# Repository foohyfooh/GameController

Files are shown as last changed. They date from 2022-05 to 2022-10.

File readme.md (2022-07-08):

# Game Controller

This is my attempt to make a custom PC game controller which has all of the regular buttons expected as well as has the ability to switch the positions of the face buttons between the Nintendo and Xbox conventions.

## [V1.0 - Initial Idea](V1.0)
- [Readme](V1.0/readme.md)
- [Schematic](V1.0/circuit.png)

This is the first iteration of the controller design based on my limited electronics experience which uses an Arduino Nano 33 BLE.

## [V1.1 - Intial Revision](V1.1)
- [Readme](V1.1/readme.md)
- [Schematic](V1.1/schematic.png)
- [Code](V1.1/code/code.ino)

This is the second iteration updated with feedback from coworkers from my inital version.

## [V1.2 - Second Revision](V1.2)
- [Readme](V1.2/readme.md)
- [Controller Schematic](V1.2/schematic-Controller.png)
- [Power Schematic](V1.2/schematic-Power.png)
- [Code](V1.2/code/code.ino)

This is the third iteration where I added in a voltage regulator component.

## [V2.0 - Third Revision](V2.0)
- [Readme](V2.0/readme.md)
- [Schematic](V2.0/schematic.png)
- [Code](V2.0/code/code.ino)

This is the fourth iteration which changes the microcontroller to the Arduino Micro since the joystick library I want to use doesn't support the Arduino Nano 33 BLE.

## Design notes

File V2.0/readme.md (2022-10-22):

# Game Controller Design Version 2.0

The main idea is to make a PC controller using [Arduino Micro](https://store.arduino.cc/products/arduino-micro), [slim buttons](https://www.adafruit.com/product/1489), [tactile buttons](https://www.adafruit.com/product/367), [vertical tactile buttons](https://www.digikey.com/en/products/detail/omron-electronics-inc-emc-div/B3F-3100/368365) and [analog sticks](https://www.adafruit.com/product/512) based on the designs below.

## Design

### Schematic
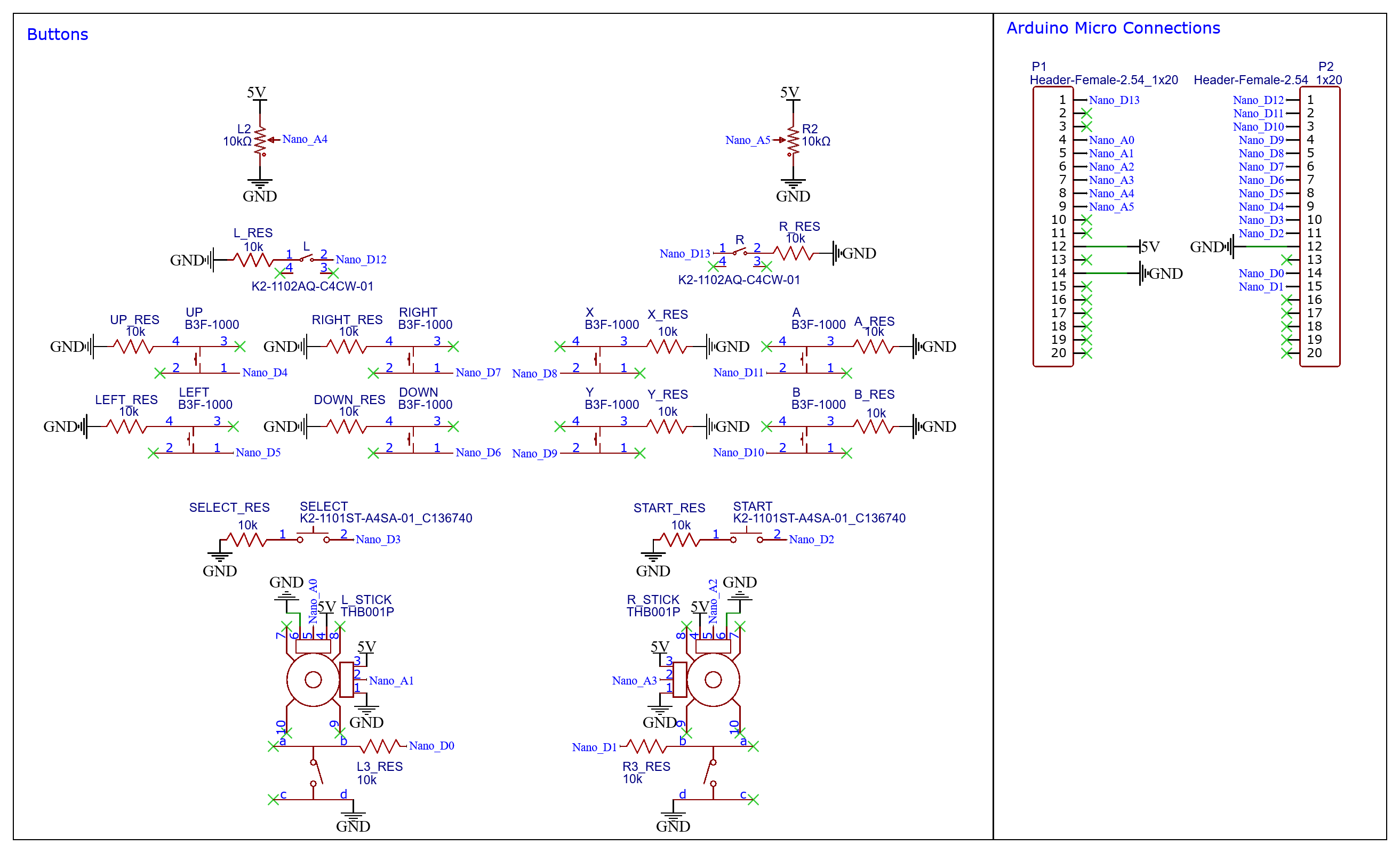
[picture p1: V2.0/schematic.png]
Schematic
 <br>
Exported from [schematic.json](schematic.json)

- The Arduino digital pins are put as INPUT_PULLUP so that when the button is closed, the signal goes to low in the digital input to register a press.
- The L2 and R2 buttons are analog while the rest of them should be digital. The L2 and R2 inputs would be using potentiometers which will require a turning mechanism when the button is pushed.

### PCB
The [PCB](pcb.json) designed from schematic is also included with the [Gerber](Gerber) files. It most likely doesn't follow best practices for routing connections but has been tested and does work.
- The intention is that the female headers allow for the Arduino to be attacched to the board without having to solder it.
- Later work needs to be done to directly connect the Arduino's microcontroller directly instead of the whole Arduino board.

### Buttons
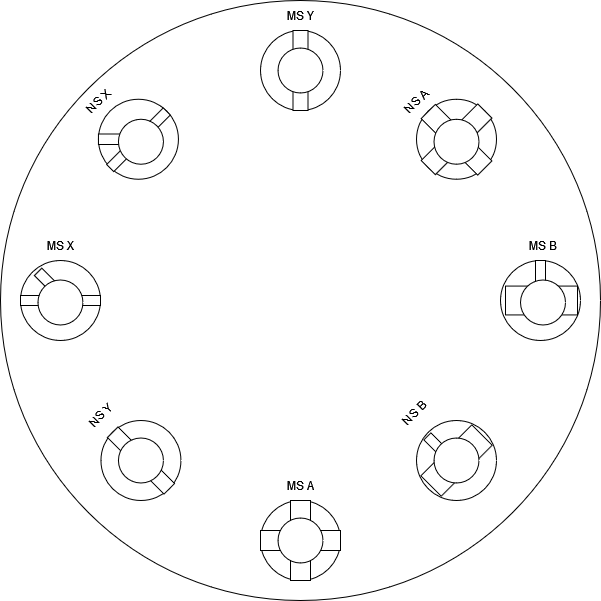
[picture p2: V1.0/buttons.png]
Buttons
 <br>
Exported from [buttons.drawio](../V1.0/buttons.drawio)

- The button holes are meant to be able to be turned 45° clockwise to switch from Nintendo layout to Xbox layout.
- The size of the holes should be different so that even if it looks similar the wrong button shouldn't able to go in the wrong hole.

## Code
Use [Matthew Heironimus'](https://github.com/MHeironimus) [Arduino Joystick Library](https://github.com/MHeironimus/ArduinoJoystickLibrary) to make [the Arduino Sketch](code/code.ino) that will act as the firmware for the controller.

## Parts
- [Arduino Micro](https://store.arduino.cc/products/arduino-micro)
- [Tactile Switch Buttons](https://www.adafruit.com/product/367)
- [Slim Tactile Switch Buttons](https://www.adafruit.com/product/1489)
- [Vertical Tactile Switch Buttons](https://www.digikey.com/en/products/detail/omron-electronics-inc-emc-div/B3F-3100/368365)
- [Analog 2-Axis Thumb Joystick with Select Button](https://www.adafruit.com/product/512)
- [10KΩ Resistors](https://www.adafruit.com/product/2784)
- [10KΩ Potentiometer](https://www.adafruit.com/product/356)

## Tool Used
- [EasyEDA](https://easyeda.com/)
- [diagrams.net](https://app.diagrams.net/)
- [Arduino IDE](https://www.arduino.cc/en/software)

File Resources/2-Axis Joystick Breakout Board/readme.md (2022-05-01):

# Analog 2-Axis Thumb Joystick with Select Button Breakout Board PCB Files

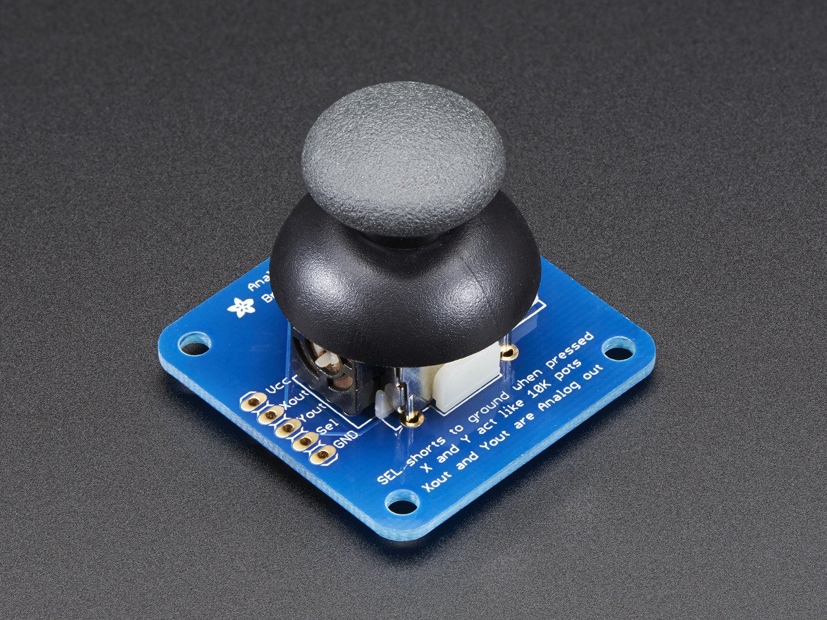
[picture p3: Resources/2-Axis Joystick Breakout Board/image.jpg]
[](http://www.adafruit.com/products/512)

This mini-kit makes it easy to mount a PSP/Xbox-like thumb joystick to your project. The thumbstick is an analog joystick - more accurate and sensitive than just 'directional' joysticks - with a 'press in to select' button. Since it's analog, you'll need two analog reading pins on your microcontroller to determine X and Y. Having an extra digital input will let you read the switch.

The pack comes in three parts - the joystick itself, a soft-touch rubber 'hat' and a nicely designed breakout board. We designed the breakout so that you can attach the joystick to a panel easily - every other breakout we wanted to carry had the mounting holes so they were in the way of the joystick movement! A 5 pin 0.1" spaced header makes it easy to connect either in a perfboard/breadboard setting or free wiring. You'll need to solder the joystick into the PCB using a soldering iron and solder, but its very simple and will only take a minute.

## License

Adafruit invests time and resources providing this open source design, please support Adafruit and open-source hardware by purchasing products from Adafruit!

Designed by Adafruit Industries.
Creative Commons Attribution, Share-Alike license, check license.txt for more information
All text above must be included in any redistribution

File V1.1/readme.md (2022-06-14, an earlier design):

# Game Controller Design Version 1.1

The main idea is to make a PC controller using [Arduino Nano 33 BLE](https://store-usa.arduino.cc/products/arduino-nano-33-ble), [slim buttons](https://www.adafruit.com/product/1489), [tactile buttons](https://www.adafruit.com/product/367), [vertical tactile buttons](https://www.digikey.com/en/products/detail/omron-electronics-inc-emc-div/B3F-3100/368365) and [analog sticks](https://www.adafruit.com/product/512) based on the designs below.

## Design

### Schematic
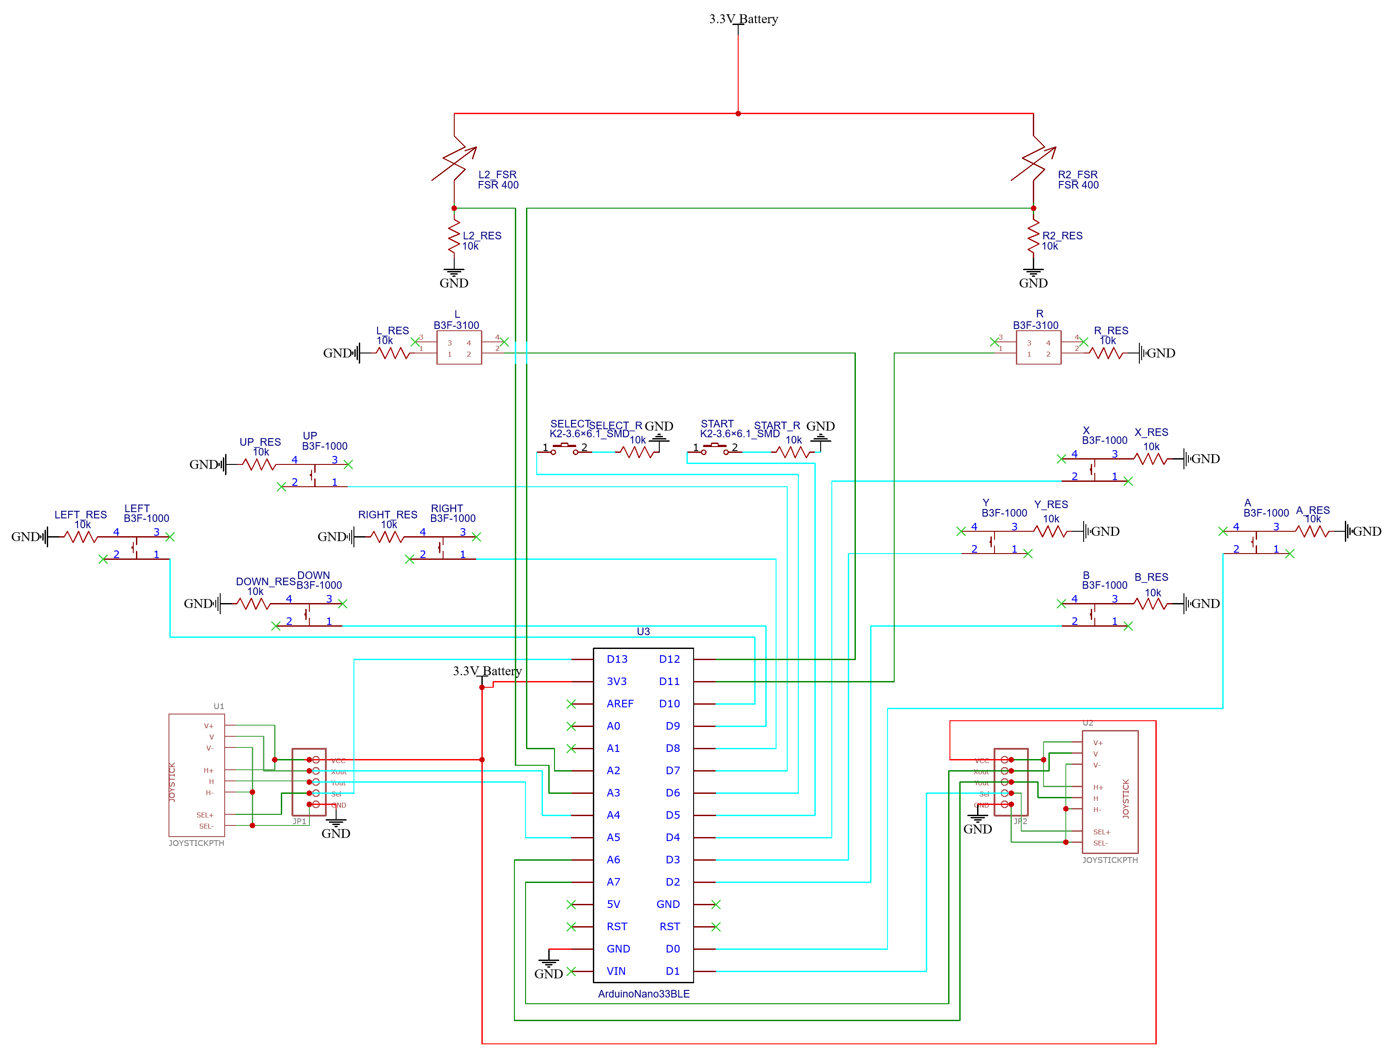
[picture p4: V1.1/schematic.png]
Schematic
 <br>
Exported from [schematic.json](schematic.json)

- The Arduino digital pins are put as INPUT_PULLUP so that when the button is closed, the signal goes to low in the digital input to register a press.
- The L2 and R2 buttons are analog while the rest of them should be digital. The L2 and R2 inputs would be using Force-Sensitive Resistors to allows the analog value to change the more the button is pushed. An alternative approach would be to use a potentiometer and turning mechanism when the button is pushed.
- Based on the [Arduino pinout diagram](../Resources/Arduino%20Nano%2033%20BLE/Pinout-NANOble_latest.pdf), I am connecting the 3.3V and GND to the +ve and -ve ends of the battery to power the Arduino.
- A voltage regulator should be put in this schematic.

### PCB
The [PCB](pcb.json) designed from schematic is also included with the [Gerber](Gerber) files. It most likely doesn't follow best practices for routing connections and needs to be tested.
- The intention is that the pads meant for the Arduino line up with the pins on the board and can be used without having to solder it.
- Later work needs to be done to directly connect a nRF52840 microcontroller instead of the whole Arduino board.

### Buttons
Buttons <br>
Exported from [buttons.drawio](../V1.0/buttons.drawio)

- The button holes are meant to be able to be turned 45° clockwise to switch from Nintendo layout to Xbox layout.
- The size of the holes should be different so that even if it looks similar the wrong button shouldn't able to go in the wrong hole.

## Code
Use [Matthew Heironimus'](https://github.com/MHeironimus) [Arduino Joystick Library](https://github.com/MHeironimus/ArduinoJoystickLibrary) to make [the Arduino Sketch](code/code.ino) that will act as the firmware for the controller.

*Note: Currently I don't have an Arduino Nano 33 BLE available so I am using an Arduino Leonardo to test my code.*

## Parts
- [Arduino Nano 33 BLE](https://store-usa.arduino.cc/products/arduino-nano-33-ble)
- [Tactile Switch Buttons](https://www.adafruit.com/product/367)
- [Slim Tactile Switch Buttons](https://www.adafruit.com/product/1489)
- [Vertical Tactile Switch Buttons](https://www.digikey.com/en/products/detail/omron-electronics-inc-emc-div/B3F-3100/368365)
- [Analog 2-Axis Thumb Joystick with Select Button](https://www.adafruit.com/product/512)
- [Round Force-Sensitive Resistor](https://www.adafruit.com/product/166)
- [10KΩ Resistors](https://www.adafruit.com/product/2784)

## Tool Used
- [EasyEDA](https://easyeda.com/)
- [diagrams.net](https://app.diagrams.net/)
- [Arduino IDE](https://www.arduino.cc/en/software)

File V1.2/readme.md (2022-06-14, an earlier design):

# Game Controller Design Version 1.2

The main idea is to make a PC controller using [Arduino Nano 33 BLE](https://store-usa.arduino.cc/products/arduino-nano-33-ble), [slim buttons](https://www.adafruit.com/product/1489), [tactile buttons](https://www.adafruit.com/product/367), [vertical tactile buttons](https://www.digikey.com/en/products/detail/omron-electronics-inc-emc-div/B3F-3100/368365) and [analog sticks](https://www.adafruit.com/product/512) based on the designs below.

## Design

### Schematic
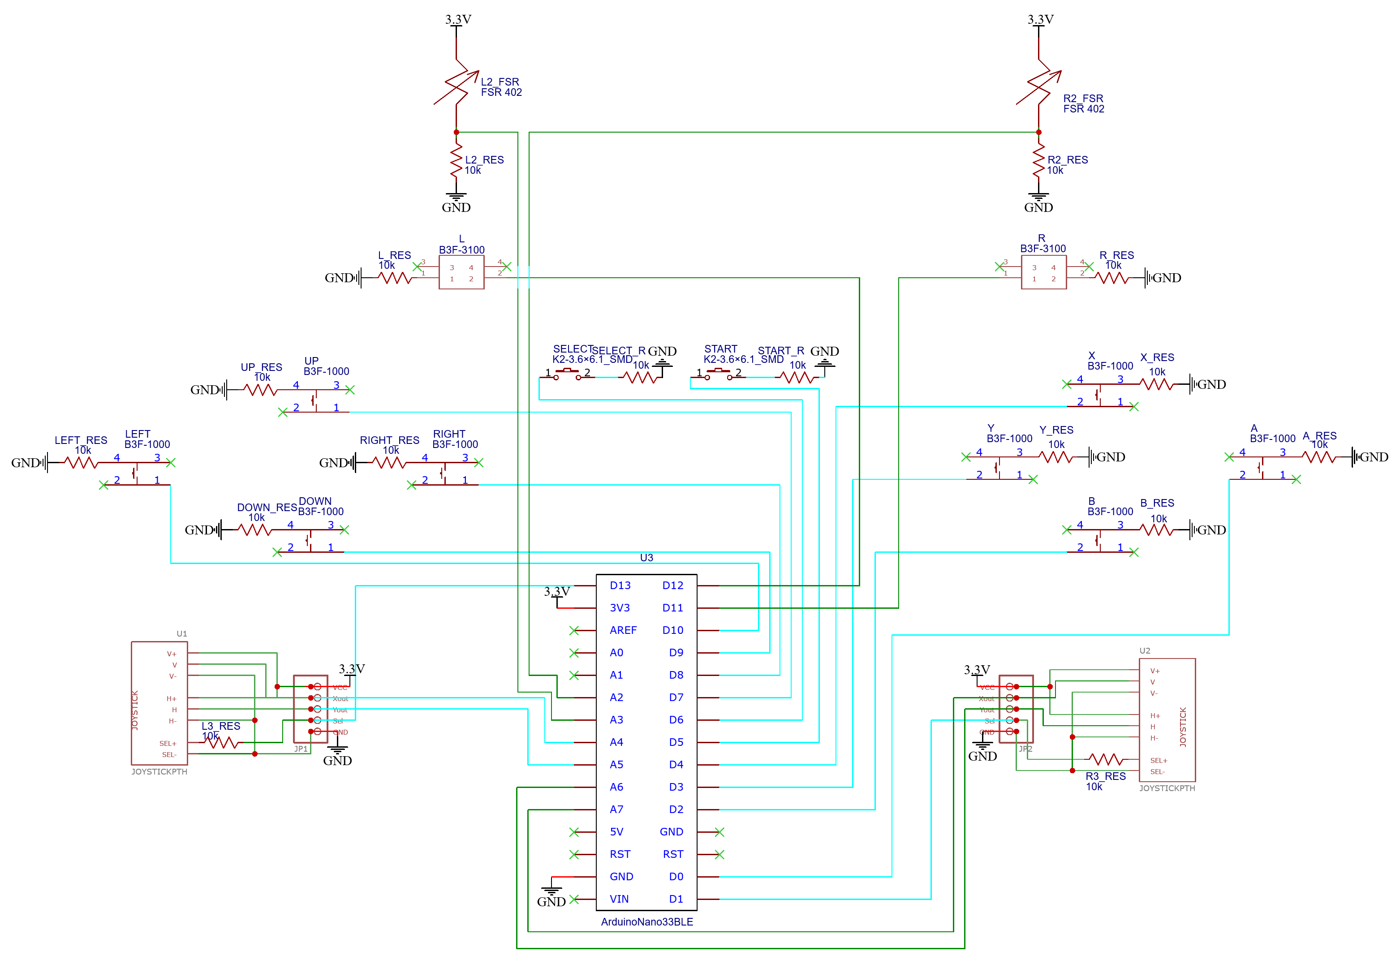
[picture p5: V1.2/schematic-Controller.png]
Controller Schematic
 <br>
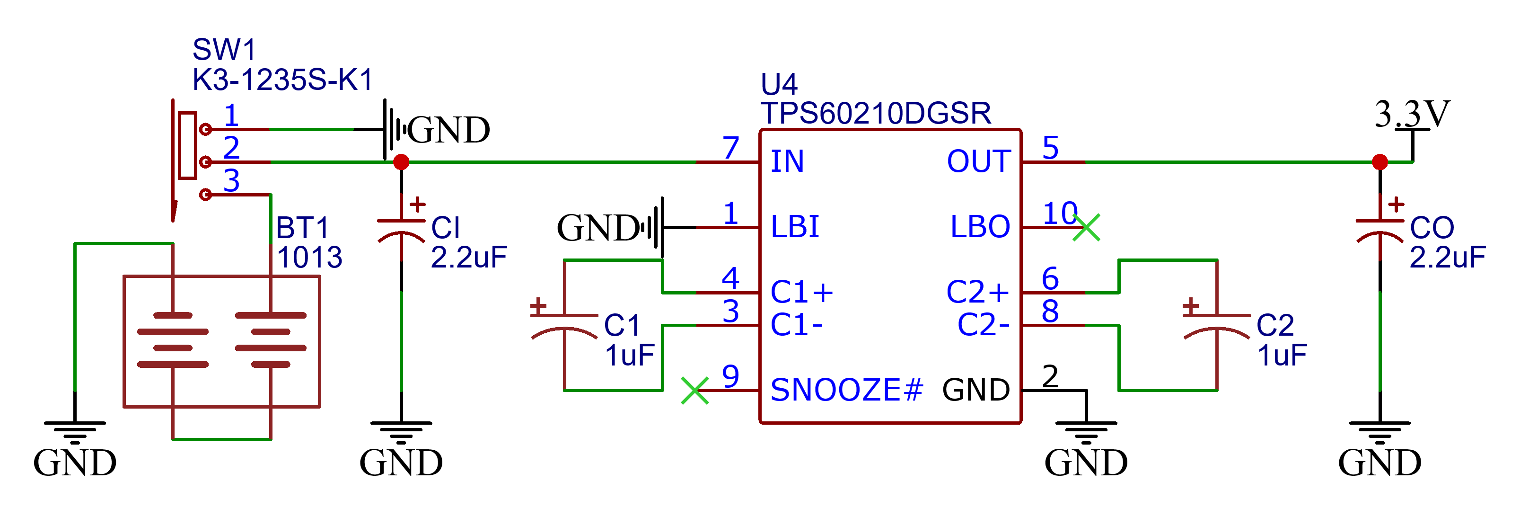
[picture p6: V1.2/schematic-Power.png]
Power Schematic
 <br>
Exported from [schematic.json](schematic.json)

- The Arduino digital pins are put as INPUT_PULLUP so that when the button is closed, the signal goes to low in the digital input to register a press.
- The L2 and R2 buttons are analog while the rest of them should be digital. The L2 and R2 inputs would be using Force-Sensitive Resistors to allows the analog value to change the more the button is pushed. An alternative approach would be to use a potentiometer and turning mechanism when the button is pushed.
- Based on the [Arduino pinout diagram](../Resources/Arduino%20Nano%2033%20BLE/Pinout-NANOble_latest.pdf), I am connecting the 3.3V and GND to the +ve and -ve ends of the battery to power the Arduino.
- I put a holder for the batteries and a voltage regulator to change the voltage from 3V to 3.3V.

### PCB
The [PCB](pcb.json) designed from schematic is also included with the [Gerber](Gerber) files. It most likely doesn't follow best practices for routing connections and needs to be tested.
- The intention is that the pads meant for the Arduino line up with the pins on the board and can be used without having to solder it.
- Later work needs to be done to directly connect the Arduino's microcontroller directly instead of the whole Arduino board.

### Buttons
Buttons <br>
Exported from [buttons.drawio](../V1.0/buttons.drawio)

- The button holes are meant to be able to be turned 45° clockwise to switch from Nintendo layout to Xbox layout.
- The size of the holes should be different so that even if it looks similar the wrong button shouldn't able to go in the wrong hole.

## Code
Use [Matthew Heironimus'](https://github.com/MHeironimus) [Arduino Joystick Library](https://github.com/MHeironimus/ArduinoJoystickLibrary) to make [the Arduino Sketch](code/code.ino) that will act as the firmware for the controller.

*Note: Currently I don't have an Arduino Nano 33 BLE available so I am using an Arduino Leonardo to test my code.*

## Parts
- [Arduino Nano 33 BLE](https://store-usa.arduino.cc/products/arduino-nano-33-ble)
- [Tactile Switch Buttons](https://www.adafruit.com/product/367)
- [Slim Tactile Switch Buttons](https://www.adafruit.com/product/1489)
- [Vertical Tactile Switch Buttons](https://www.digikey.com/en/products/detail/omron-electronics-inc-emc-div/B3F-3100/368365)
- [Analog 2-Axis Thumb Joystick with Select Button](https://www.adafruit.com/product/512)
- [Round Force-Sensitive Resistor](https://www.adafruit.com/product/166)
- [10KΩ Resistors](https://www.adafruit.com/product/2784)

## Tool Used
- [EasyEDA](https://easyeda.com/)
- [diagrams.net](https://app.diagrams.net/)
- [Arduino IDE](https://www.arduino.cc/en/software)

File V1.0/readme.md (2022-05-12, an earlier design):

# Game Controller Design Version 1.0

The main idea is to make a PC controller using [Arduino Nano 33 BLE](https://store-usa.arduino.cc/products/arduino-nano-33-ble), [slim buttons](https://www.adafruit.com/product/1489), [tactile buttons](https://www.adafruit.com/product/367), [vertical tactile buttons](https://www.digikey.com/en/products/detail/omron-electronics-inc-emc-div/B3F-3100/368365) and [analog sticks](https://www.adafruit.com/product/512) based on the designs below.

## Design
### Circuit
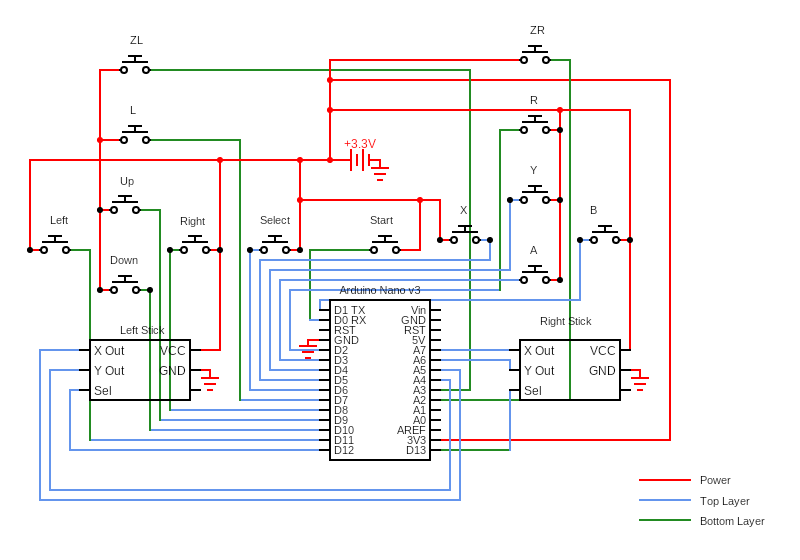
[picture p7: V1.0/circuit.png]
Circuit Diagram
 <br>
Exported from [circuit.ccddx](circuit.cddx)

- When the button is closed, the signal goes to high in the digital input to register a press.
- The ZL and ZR buttons are analog while all of the rest of them should be digital.
- Based on the [Arduino pinout diagram](../Resources/Arduino%20Nano%2033%20BLE/Pinout-NANOble_latest.pdf), I am connecting the 3.3V and GND to the +ve and -ve ends of the battery to power the Arduino.

### Buttons
Buttons <br>
Exported from [buttons.drawio](buttons.drawio)

- The button holes are meant to be able to be turned 45° clockwise to switch from Xbox layout to Nintendo layout.
- The size of the holes should be different so that even if it looks similar the wrong button shouldn't able to go in the wrong hole.

## Parts
- [Arduino Nano 33 BLE](https://store-usa.arduino.cc/products/arduino-nano-33-ble)
- [Tactile Switch Buttons](https://www.adafruit.com/product/367)
- [Slim Tactile Switch Buttons](https://www.adafruit.com/product/1489)
- [Vertical Tactile Switch Buttons](https://www.digikey.com/en/products/detail/omron-electronics-inc-emc-div/B3F-3100/368365)
- [Analog 2-Axis Thumb Joystick with Select Button](https://www.adafruit.com/product/512)
- [Round Force-Sensitive Resistor](https://www.adafruit.com/product/166)
- [Resistors](https://www.adafruit.com/product/2781)

## Tool Used
- [Circuit Diagram Web Editor](https://www.circuit-diagram.org/editor/)
- [diagrams.net](https://app.diagrams.net/)

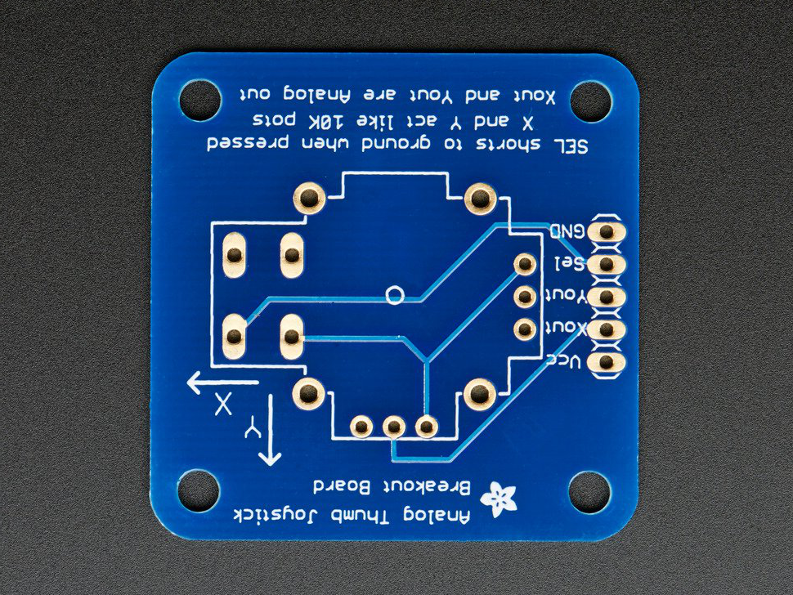
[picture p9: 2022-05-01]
Resources/2-Axis Joystick Breakout Board/breakoutboard-180.jpg

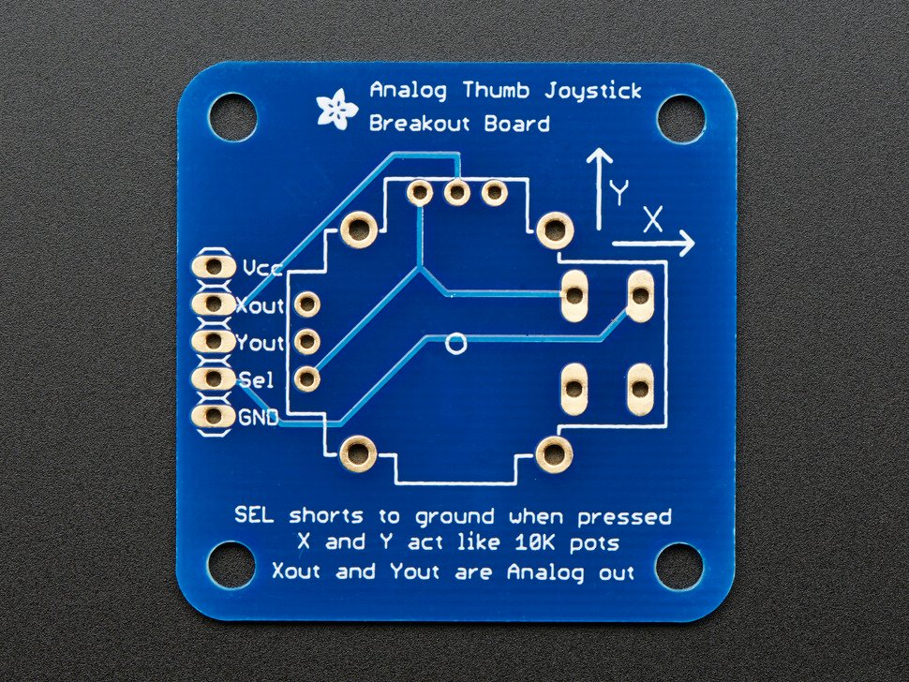
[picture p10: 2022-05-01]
Resources/2-Axis Joystick Breakout Board/breakoutboard.jpg

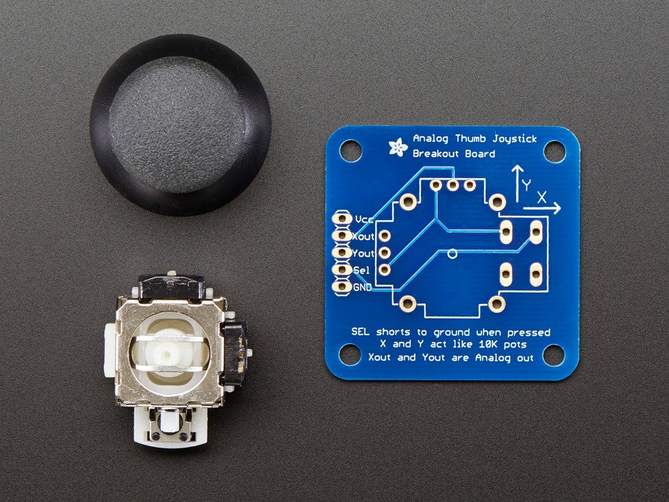
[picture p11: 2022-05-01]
Resources/2-Axis Joystick Breakout Board/breakoutboard and joystick.jpg

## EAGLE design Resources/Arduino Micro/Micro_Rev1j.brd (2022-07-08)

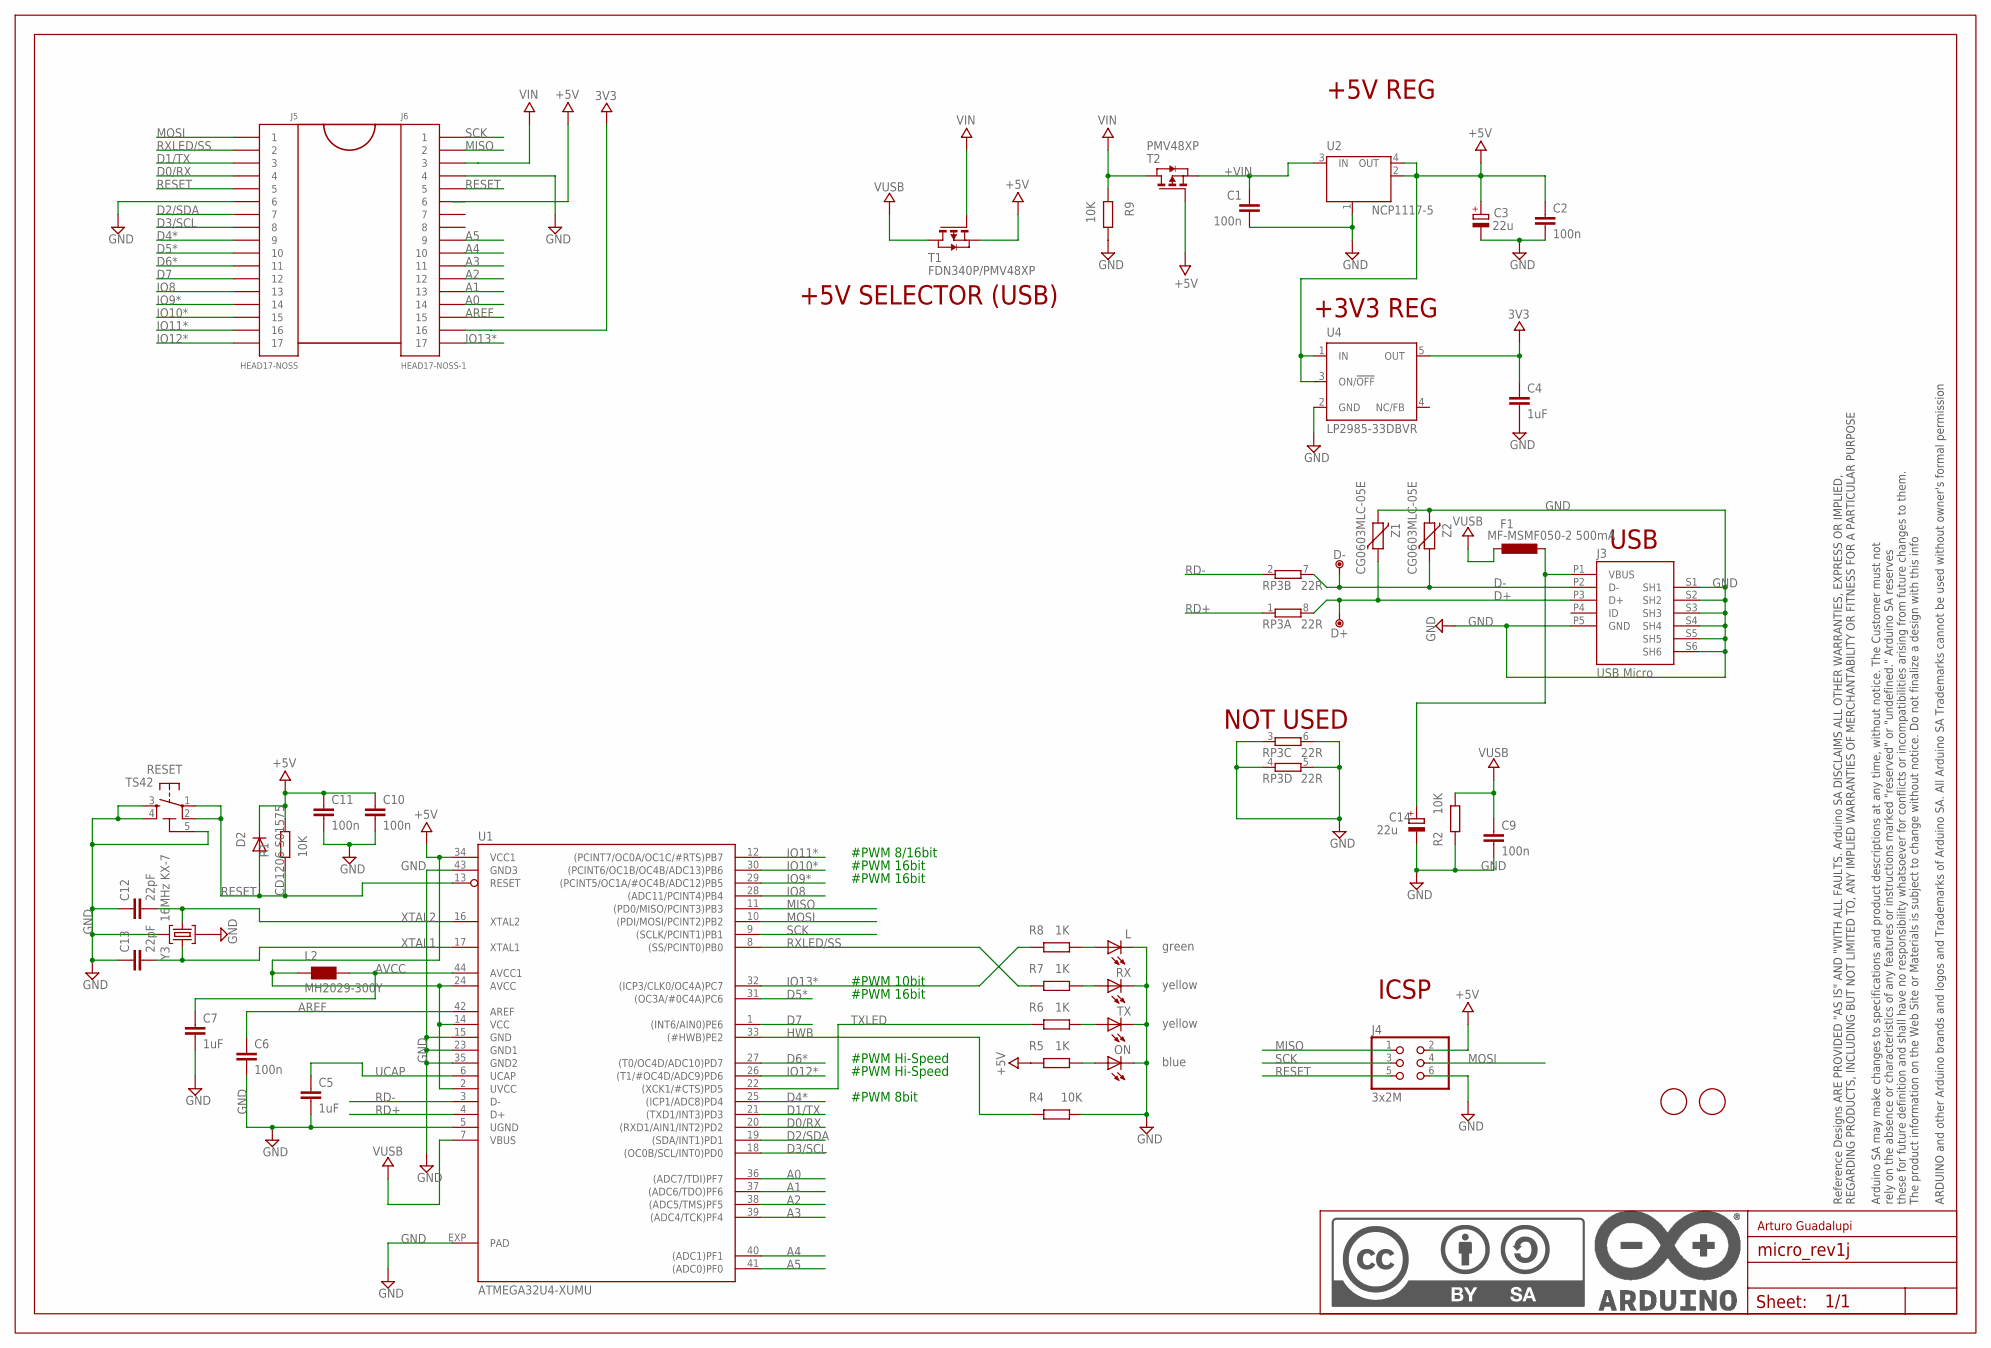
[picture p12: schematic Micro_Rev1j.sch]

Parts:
C1, C2, C6, C9, C10, C11: 100n; C0402
C3, C14: 22u; SMC_B
C4, C5, C7: 1uF; C0402
C12, C13: 22pF; C0402
D2: CD1206-S01575; MINIMELF
D+: DNP; TP-1.00MM
D-: DNP; TP-1.00MM
F1: MF-MSMF050-2 500mA; L1812
FRAME1: DNP; FRAME
J3: USB Micro; CON2_USB_MICRO_B_AT
J4: 3x2M; 2X03
J5: HEAD17-NOSS
J6: HEAD17-NOSS-1
L: green; CHIPLED_0805
L2: MH2029-300Y; 0805
ON: blue; CHIPLED_0805
R1, R2, R4, R9: 10K; R0402
R5, R6, R7, R8: 1K; R0402
RESET: TS42
RP3: 22R; CAY16
RX: yellow; CHIPLED_0805
T1: FDN340P/PMV48XP; SOT-23
T2: PMV48XP; SOT-23
TX: yellow; CHIPLED_0805
U1: ATMEGA32U4-XUMU; QFN44ML7X7
U2: NCP1117-5; SOT223
U4: LP2985-33DBVR; SOT23-DBV
U$37, U$53: DNP; FD-1-1.5
Y3: 16MHz KX-7; CRYSTAL-3.2-2.5
Z1, Z2: CG0603MLC-05E; CT/CN0603

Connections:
3V3: C4.1, J6.16, U4.5 (OUT)
+5V: C2.1, C3.+, C10.1, C11.1, D2.C, J4.2, J6.6, L2.1, R1.1, R5.1, T1.2 (S), T2.3 (G), U1.2 (UVCC), U1.14 (VCC), U1.24 (AVCC), U1.34 (VCC1), U2.2 (OUT), U2.4 (OUT), U4.1 (IN), U4.3 (ON/!OFF)
+VIN: C1.1, T2.2 (S), U2.3 (IN)
A0: J6.14, U1.36 ((ADC7/TDI)PF7)
A1: J6.13, U1.37 ((ADC6/TDO)PF6)
A2: J6.12, U1.38 ((ADC5/TMS)PF5)
A3: J6.11, U1.39 ((ADC4/TCK)PF4)
A4: J6.10, U1.40 ((ADC1)PF1)
A5: J6.9, U1.41 ((ADC0)PF0)
AREF: C6.1, J6.15, U1.42 (AREF)
AVCC: C7.1, L2.2, U1.44 (AVCC1)
D0/RX: J5.4, U1.20 ((RXD1/AIN1/INT2)PD2)
D1/TX: J5.3, U1.21 ((TXD1/INT3)PD3)
D2/SDA: J5.7, U1.19 ((SDA/INT1)PD1)
D3/SCL: J5.8, U1.18 ((OC0B/SCL/INT0)PD0)
D4*: J5.9, U1.25 ((ICP1/ADC8)PD4)
D5*: J5.10, U1.31 ((OC3A/#0C4A)PC6)
D6*: J5.11, U1.27 ((T0/OC4D/ADC10)PD7)
D7: J5.12, U1.1 ((INT6/AIN0)PE6)
D+: D+.X, J3.P3 (D+), RP3.8 (2), Z1.1
D-: D-.X, J3.P2 (D-), RP3.7 (2), Z2.1
GND: C1.2, C2.2, C3.-, C4.2, C5.2, C6.2, C7.2, C9.2, C10.2, C11.2, C12.1, C13.1, C14.-, J3.P5 (GND), J3.S1 (SH1), J3.S2 (SH2), J3.S3 (SH3), J3.S4 (SH4), J3.S5 (SH5), J3.S6 (SH6), J4.6, J5.6, J6.4, L.C, ON.C, R2.1, R4.2, R9.1, RESET.3, RESET.4, RESET.5 (5-GND), RP3.3 (1), RP3.4 (1), RP3.5 (2), RP3.6 (2), RX.C, TX.C, U1.5 (UGND), U1.15 (GND), U1.23 (GND1), U1.35 (GND2), U1.43 (GND3), U1.EXP (PAD), U2.1 (GND/ADJ), U4.2 (GND), Y3.2 (GND), Y3.4 (GND), Z1.2, Z2.2
HWB: R4.1, U1.33 ((#HWB)PE2)
IO8: J5.13, U1.28 ((ADC11/PCINT4)PB4)
IO9*: J5.14, U1.29 ((PCINT5/OC1A/#OC4B/ADC12)PB5)
IO10*: J5.15, U1.30 ((PCINT6/OC1B/OC4B/ADC13)PB6)
IO11*: J5.16, U1.12 ((PCINT7/OC0A/OC1C/#RTS)PB7)
IO12*: J5.17, U1.26 ((T1/#OC4D/ADC9)PD6)
IO13*: J6.17, R8.1, U1.32 ((ICP3/CLK0/OC4A)PC7)
MISO: J4.1, J6.2, U1.11 ((PD0/MISO/PCINT3)PB3)
MOSI: J4.4, J5.1, U1.10 ((PDI/MOSI/PCINT2)PB2)
unnamed: R7.2, RX.A
unnamed: ON.A, R5.2
unnamed: R6.2, TX.A
unnamed: L.A, R8.2
RD+: RP3.1, U1.4 (D+)
RD-: RP3.2 (1), U1.3 (D-)
RESET: D2.A, J4.5, J5.5, J6.5, R1.2, RESET.1, RESET.2, U1.13 (RESET)
RXLED/SS: J5.2, R7.1, U1.8 ((SS/PCINT0)PB0)
SCK: J4.3, J6.1, U1.9 ((SCLK/PCINT1)PB1)
TXLED: R6.1, U1.22 ((XCK1/#CTS)PD5)
UCAP: C5.1, U1.6 (UCAP)
VIN: J6.3, R9.2, T1.3 (G), T2.1 (D)
VUSB: C9.1, F1.2, R2.2, T1.1 (D), U1.7 (VBUS)
VUSBD: C14.+, F1.1, J3.P1 (VBUS)
XTAL1: C13.2, U1.17 (XTAL1), Y3.3 (C2)
XTAL2: C12.2, U1.16 (XTAL2), Y3.1 (C1)

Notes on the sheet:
+5V REG
ICSP
USB
+5V SELECTOR (USB)
NOT USED
+3V3 REG
#PWM 8bit
#PWM Hi-Speed
#PWM 16bit
#PWM 10bit
#PWM 8/16bit
Arturo Guadalupi

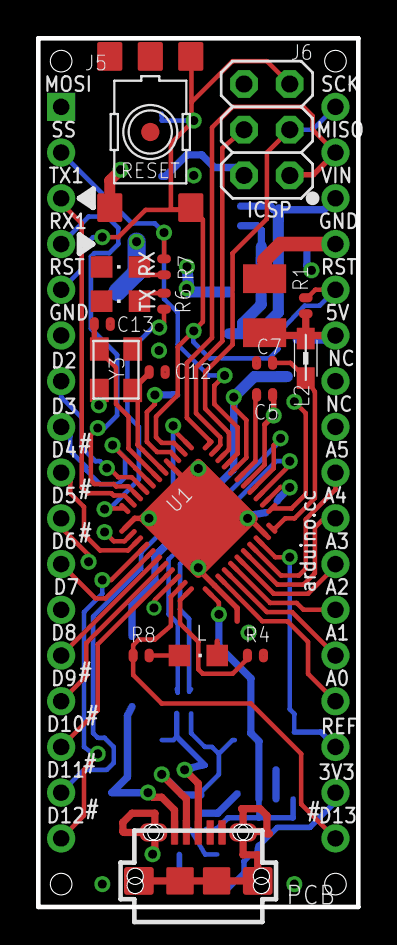
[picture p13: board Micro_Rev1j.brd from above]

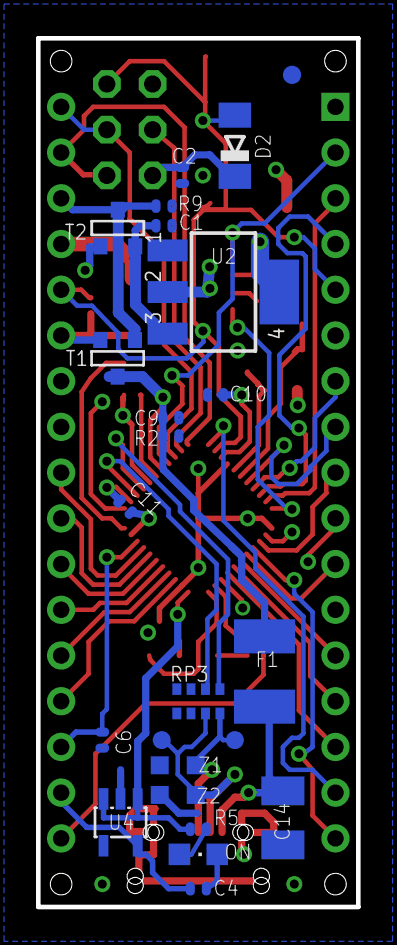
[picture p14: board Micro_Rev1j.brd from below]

Board: 4 copper layers, 17.8 x 48.3 mm, 47 parts (22 on the bottom side), 47 nets.

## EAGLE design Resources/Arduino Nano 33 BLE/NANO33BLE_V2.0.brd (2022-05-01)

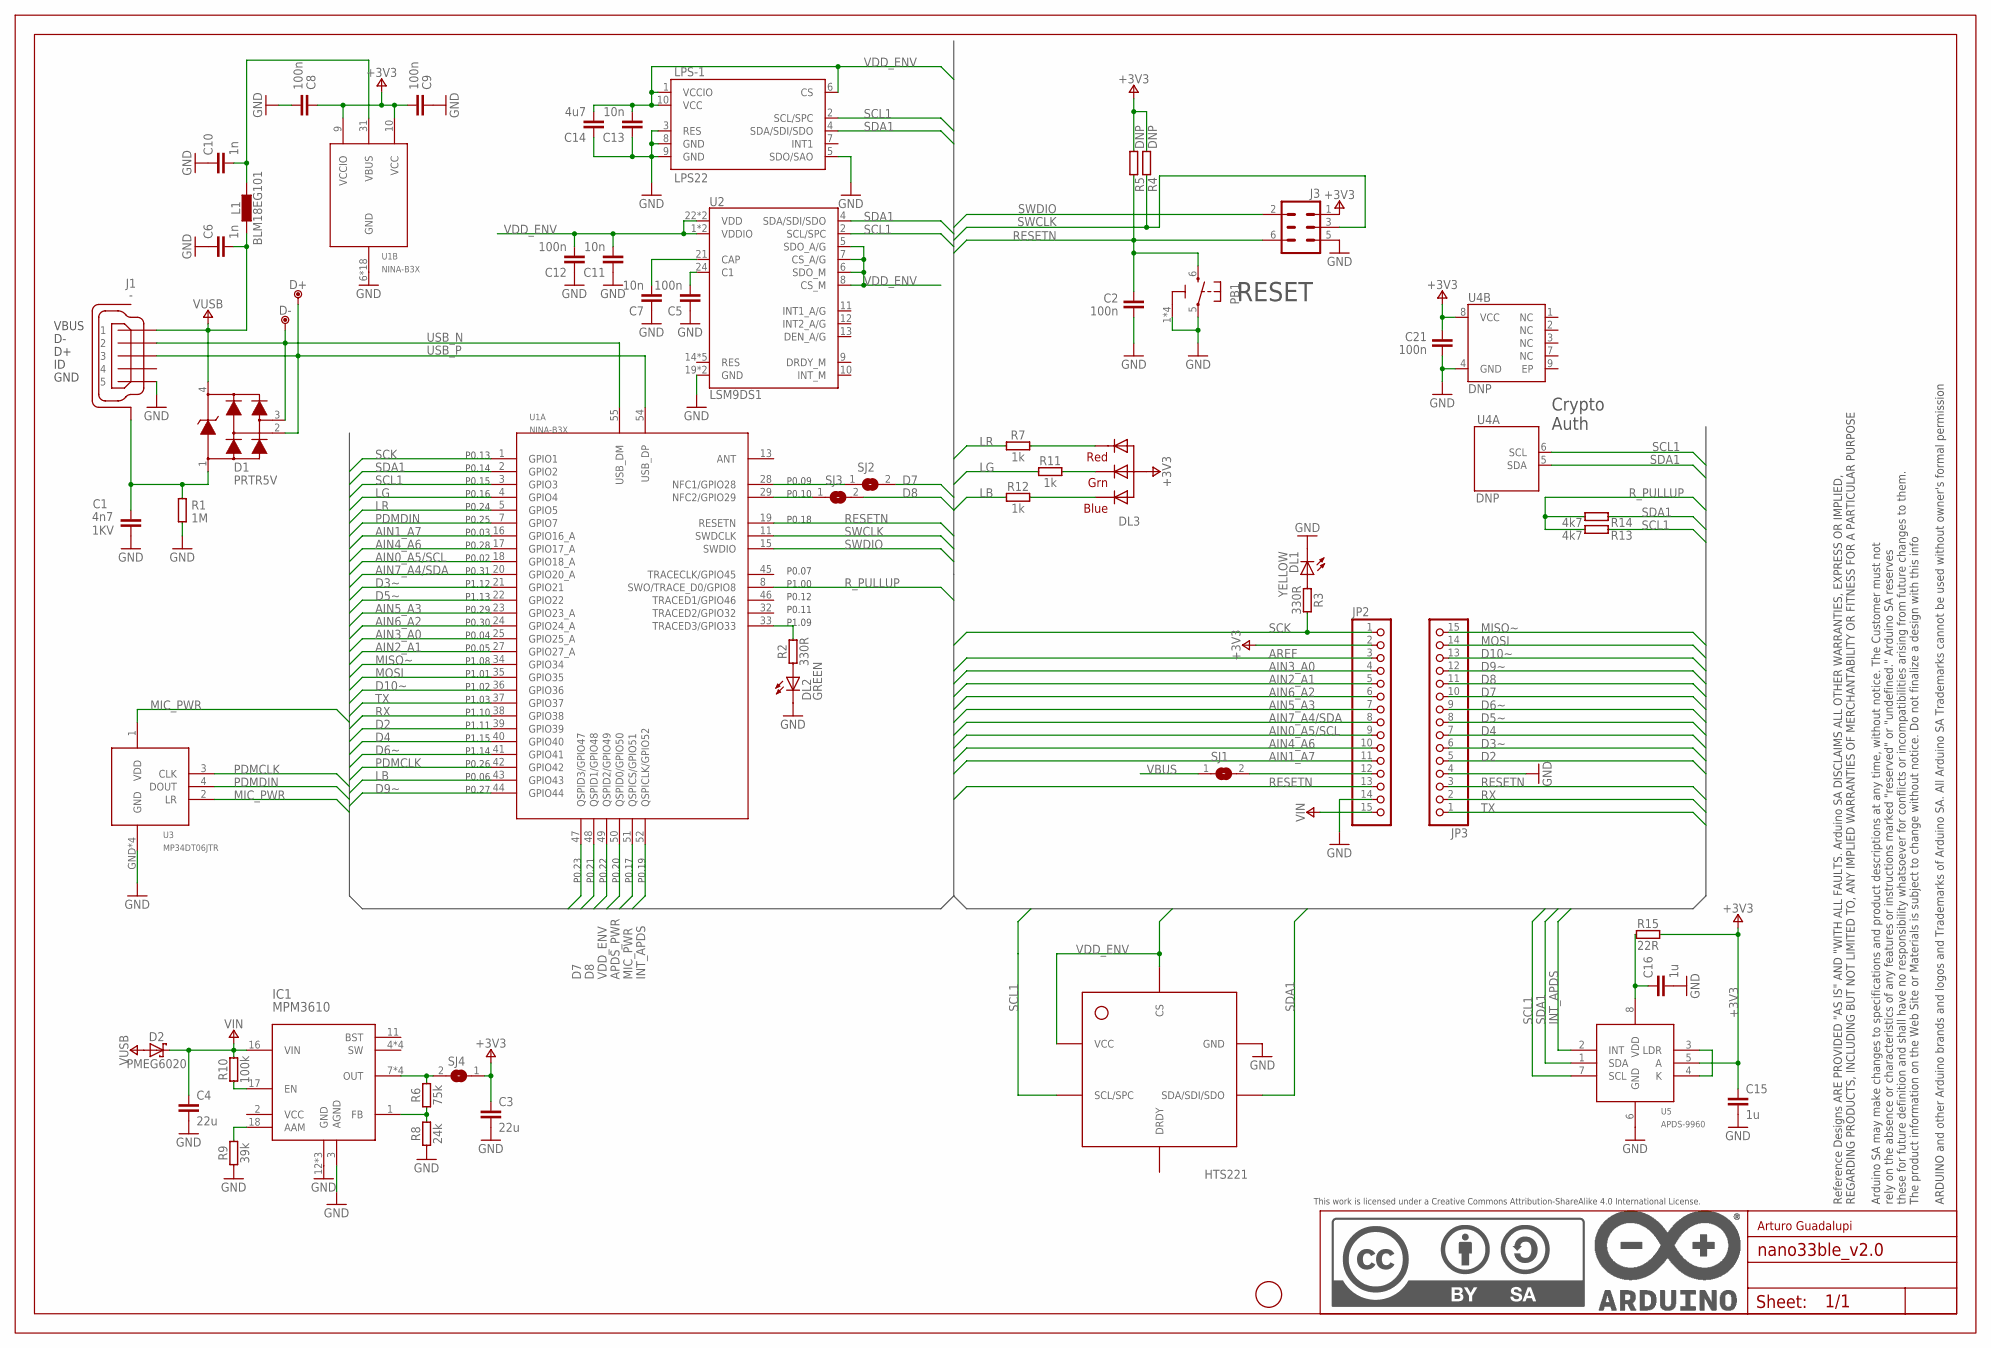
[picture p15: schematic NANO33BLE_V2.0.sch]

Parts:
C1: 4n7; 0805-R2013X50N; VOLTAGE 1KV
C2, C5, C8, C9, C12, C21: 100n; 0402-1005X55N
C3, C4: 22u; 0805-R2013X50N
C6, C10: 1n; 0402-1005X55N
C7, C11, C13: 10n; 0402-1005X55N
C14: 4u7; 0402-1005X55N
C15, C16: 1u; 0402-1005X55N
D1: PRTR5V; SOT190P230X110-4N
D2: PMEG6020; SODFL3517X110N
D+: DNP; TP-1.00MM
D-: DNP; TP-1.00MM
DL1: YELLOW; LEDC1608X80N-AK
DL2: GREEN; LEDC1608X80N-AK
DL3: -; SMLP34RGB2W
FD1: DNP; FD-1-1.5
FRAME1: DNP; FRAME
HS-1: HTS221
IC1: MPM3610
J1: -; ZX62-AB-5PA
J3: DNP; 2X03-TP1
JP2, JP3: PINHD-1X15-CASTELLATED; 1X15-CASTELL
L1: BLM18EG101; 0603-1608X90N
LPS-1: LPS22; LPS22H
PB1: PTS820; C&K_PTS820_NO_HOLES
R1: 1M; 0402-1005X55N
R2, R3: 330R; 0402-1005X55N
R4, R5: DNP; 0402-1005X55N
R6: 75k; 0402-1005X55N
R7, R11, R12: 1k; 0402-1005X55N
R8: 24k; 0402-1005X55N
R9: 39k; 0402-1005X55N
R10: 100k; 0402-1005X55N
R13, R14: 4k7; 0402-1005X55N
R15: 22R; 0402-1005X55N
SJ1, SJ2, SJ3, SJ4: DNP; SJ
U1: NINA-B3X
U2: LSM9DS1; LSM9DS1_TEMP_LGA24-8X4
U3: MP34DT06JTR; HCLGA
U4: DNP; SON50P300X200X60-9N-EP160X140
U5: APDS-9960; APDS9960

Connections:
+3V3: C3.1, C8.1, C9.2, C15.1, C21.1, DL3.1 (A), J3.1, JP2.2, R4.2, R5.2, R15.2, SJ4.1, U1.9 (VCCIO), U1.10 (VCC), U4.8 (VCC), U5.5 (A)
AIN0_A5/SCL: JP2.9, U1.18 (GPIO18_A)
AIN1_A7: JP2.11, U1.16 (GPIO16_A)
AIN2_A1: JP2.5, U1.27 (GPIO27_A)
AIN3_A0: JP2.4, U1.25 (GPIO25_A)
AIN4_A6: JP2.10, U1.17 (GPIO17_A)
AIN5_A3: JP2.7, U1.23 (GPIO23_A)
AIN6_A2: JP2.6, U1.24 (GPIO24_A)
AIN7_A4/SDA: JP2.8, U1.20 (GPIO20_A)
APDS_PWR: U1.50 (QSPID0/GPIO50)
AREF: JP2.3
D2: JP3.5, U1.39 (GPIO39)
D3~: JP3.6, U1.21 (GPIO21)
D4: JP3.7, U1.40 (GPIO40)
D5~: JP3.8, U1.22 (GPIO22)
D6~: JP3.9, U1.41 (GPIO41)
D7: JP3.10, SJ2.2, U1.47 (QSPID3/GPIO47)
D8: JP3.11, SJ3.2, U1.48 (QSPID1/GPIO48)
D9~: JP3.12, U1.44 (GPIO44)
D10~: JP3.13, U1.36 (GPIO36)
GND: C1.2, C2.2, C3.2, C4.2, C5.1, C6.1, C7.1, C8.2, C9.1, C10.1, C11.1, C12.1, C13.1, C14.1, C15.2, C16.2, C21.2, DL1.C, DL2.C, HS-1.P$5.GND (GND), IC1.3 (AGND), IC1.12 (GND), IC1.13 (GND), IC1.14 (GND), J1.5, J3.5, JP2.14, JP3.4, LPS-1.3 (RES), LPS-1.5 (SDO/SAO), LPS-1.8 (GND), LPS-1.9 (GND), PB1.1 (3), PB1.2 (3), PB1.3, PB1.4 (3), PB1.5 (1), R1.1, R8.1, R9.1, U1.6 (GND), U1.12 (GND), U1.14 (GND), U1.26 (GND), U1.30 (GND), U1.53 (GND), U1.GND@1 (GND), U1.GND@2 (GND), U1.GND@3 (GND), U1.GND@4 (GND), U1.GND@5 (GND), U1.GND@6 (GND), U1.GND@7 (GND), U1.GND@8 (GND), U1.GND@9 (GND), U1.GND@10 (GND), U1.GND@11 (GND), U1.GND@12 (GND), U2.19 (GND), U2.20 (GND), U3.GND, U3.GND@2 (GND), U3.GND@3 (GND), U3.GND@4 (GND), U4.4 (GND), U5.6 (GND)
INT_APDS: U1.52 (QSPICLK/GPIO52), U5.2 (INT)
LB: R12.1, U1.43 (GPIO43)
LG: R11.1, U1.4 (GPIO4)
LR: R7.1, U1.5 (GPIO5)
MIC_PWR: U1.51 (QSPICS/GPIO51), U3.1 (VDD), U3.2 (LR)
MISO~: JP3.15, U1.34 (GPIO34)
MOSI: JP3.14, U1.35 (GPIO35)
unnamed: C1.1, D1.1, J1.6 (SH), J1.7 (SH), J1.8 (SH), J1.9 (SH), J1.10 (SH), J1.11 (SH), R1.2
unnamed: DL2.A, R2.1
unnamed: DL1.A, R3.1
unnamed: C5.2, U2.24 (C1)
unnamed: IC1.1 (FB), R6.1, R8.2
unnamed: IC1.18 (AAM), R9.2
unnamed: IC1.17 (EN), R10.1
unnamed: C7.2, U2.21 (CAP)
unnamed: U5.3 (LDR), U5.4 (K)
unnamed: R2.2, U1.33 (TRACED3/GPIO33)
unnamed: DL3.3 (BLUE_C), R12.2
unnamed: DL3.2 (RED_C), R7.2
unnamed: DL3.4 (GREEN_C), R11.2
unnamed: JP2.12, SJ1.2
unnamed: C16.1, R15.1, U5.8 (VDD)
unnamed: IC1.7 (OUT), IC1.8 (OUT), IC1.9 (OUT), IC1.20 (OUT), R6.2, SJ4.2
NFC1: SJ2.1, U1.28 (NFC1/GPIO28)
NFC2: SJ3.1, U1.29 (NFC2/GPIO29)
PDMCLK: U1.42 (GPIO42), U3.3 (CLK)
PDMDIN: U1.7 (GPIO7), U3.4 (DOUT)
RESETN: C2.1, J3.6, JP2.13, JP3.3, PB1.6 (2), R5.1, U1.19 (RESETN)
RX: JP3.2, U1.38 (GPIO38)
R_PULLUP: R13.2, R14.2, U1.8 (SWO/TRACE_D0/GPIO8)
SCK: JP2.1, R3.2, U1.1 (GPIO1)
SCL1: HS-1.P$2.SCL/SPC (SCL/SPC), LPS-1.2 (SCL/SPC), R13.1, U1.3 (GPIO3), U2.2 (SCL/SPC), U4.6 (SCL), U5.7 (SCL)
SDA1: HS-1.P$4.SDA/SDI/SDO (SDA/SDI/SDO), LPS-1.4 (SDA/SDI/SDO), R14.1, U1.2 (GPIO2), U2.4 (SDA/SDI/SDO), U4.5 (SDA), U5.1 (SDA)
SWCLK: J3.3, R4.1, U1.11 (SWDCLK)
SWDIO: J3.2, U1.15 (SWDIO)
TX: JP3.1, U1.37 (GPIO37)
USB_N: D1.3, D-.X, J1.2, U1.55 (USB_DM)
USB_P: D1.2, D+.X, J1.3, U1.54 (USB_DP)
VBUS: C10.2, L1.2, SJ1.1, U1.31 (VBUS)
VDD_ENV: C11.2, C12.2, C13.2, C14.2, HS-1.P$1.VDD (VCC), HS-1.P$6.CS (CS), LPS-1.1 (VCCIO), LPS-1.6 (CS), LPS-1.10 (VCC), U1.49 (QSPID2/GPIO49), U2.1 (VDDIO), U2.3 (VDDIO), U2.5 (SDO_A/G), U2.6 (SDO_M), U2.7 (CS_A/G), U2.8 (CS_M), U2.22 (VDD), U2.23 (VDD)
VIN: C4.1, D2.C, IC1.16 (VIN), JP2.15, R10.2
VUSB: C6.2, D1.4, D2.A, J1.1, L1.1

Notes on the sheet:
RESET
Crypto Auth
Arturo Guadalupi
HTS221

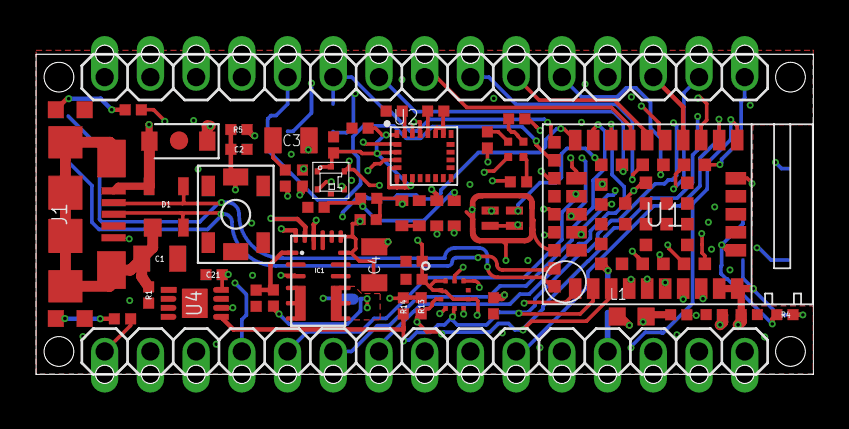
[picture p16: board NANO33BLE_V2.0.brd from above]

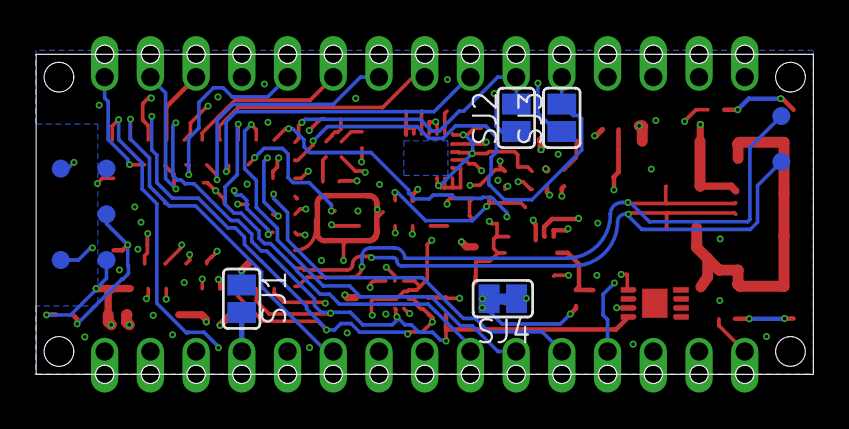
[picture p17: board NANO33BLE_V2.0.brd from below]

Board: 4 copper layers, 43.2 x 17.8 mm, 59 parts (4 on the bottom side), 61 nets.

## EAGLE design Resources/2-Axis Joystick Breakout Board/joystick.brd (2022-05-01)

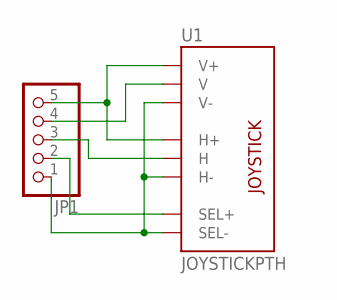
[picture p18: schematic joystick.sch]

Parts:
JP1: PINHD-1X5; 1X05
U1: JOYSTICKPTH; JOYSTICK

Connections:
unnamed: JP1.5, U1.H1 (H+), U1.V1 (V+)
unnamed: JP1.1, U1.B2A (SEL-), U1.H3 (H-), U1.V3 (V-)
unnamed: JP1.4, U1.V2 (V)
unnamed: JP1.3, U1.H2 (H)
unnamed: JP1.2, U1.B1A (SEL+)

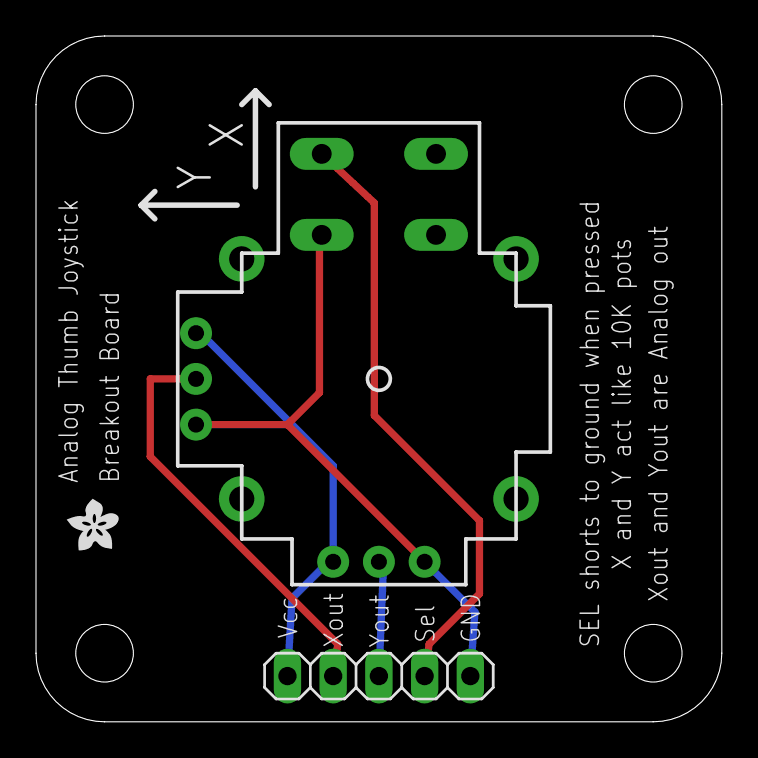
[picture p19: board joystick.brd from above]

Board: 2 copper layers, 38.1 x 38.1 mm, 3 parts (0 on the bottom side), 5 nets.

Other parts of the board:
U$1: ADAFRUIT200MIL

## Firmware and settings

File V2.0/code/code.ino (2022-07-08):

// Conventions followed based on a mix of
// Xbox Core Wireless Controller/Logitech F310 Gamepad: Face Buttons Naming Convention and HID outputs in the Windows Game Controllers tool
// Nintendo Switch Controller: Bumpers Naming Convention
// Sony DualShock 4 Controller: Triggers and Stick Buttons Naming Convention
#include <Joystick.h>

#define DEBUG             true
#define MAP_ANALOG        (!DEBUG || true)
#define USE_DEADZONE      true
#define SEPARATE_TRIGGERS false

// Buttons
const int NUM_BUTTONS = 10;
int pinToButton    [NUM_BUTTONS] = { 11,  10,   8,   9,  12,  13,        3,       2,   0,     1};
String buttonName  [NUM_BUTTONS] = {"A", "B", "X", "Y", "L", "R", "Select", "Start", "L3", "R3"};
int lastButtonState[NUM_BUTTONS] = {0, 0, 0, 0, 0, 0, 0, 0, 0, 0};

// D-Pad
const int NUM_HATS = 1;
const int HAT_INDEX = 0;
const int NUM_HAT_BUTTONS = 4;
int pinToHat    [NUM_HAT_BUTTONS] = {   4,       7,      6,      5};
String hatName  [NUM_HAT_BUTTONS] = {"Up", "Right", "Down", "Left"};
int lastHatState[NUM_HAT_BUTTONS] = {0, 0, 0, 0};
int lastHatAngle = JOYSTICK_HATSWITCH_RELEASE;

// Analog Sticks and Triggers
// Using X axis and Y axis for left movement stick
// Using Rx axis and Ry axis for right stick
// Using either Z axis and Rz axis or Z axis alone for trigger switches
const int NUM_ANALOG = 6;
const int JOYSTICK_POS = 4;
int pinToAnalog    [NUM_ANALOG] = {            A0,             A1,              A2,              A3,   A4,   A5};
String analogName  [NUM_ANALOG] = {"Left Stick X", "Left Stick Y", "Right Stick X", "Right Stick Y", "L2", "R2"};
int lastAnalogState[NUM_ANALOG] = {0, 0, 0, 0, 0, 0};

#define STICK_MIN        10
#define STICK_MAX      1020
#define STICK_DEADZONE   20
#define POT_MIN          10
#define POT_MAX        1020
#define LIB_MIN        JOYSTICK_DEFAULT_AXIS_MINIMUM
#define LIB_MAX        JOYSTICK_DEFAULT_AXIS_MAXIMUM
int pinRange[NUM_ANALOG][2] = {{STICK_MIN, STICK_MAX}, {STICK_MIN, STICK_MAX}, {STICK_MIN, STICK_MAX}, {STICK_MIN, STICK_MAX}, {POT_MIN, POT_MAX}, {POT_MIN, POT_MAX}};

// Create the Joystick
#define HAS_X_AXIS      true
#define HAS_Y_AXIS      true
#define HAS_Z_AXIS      true
#define HAS_RX_AXIS     true
#define HAS_RY_AXIS     true
#define HAS_RZ_AXIS     SEPARATE_TRIGGERS
#define HAS_RUDDER      false
#define HAS_THROTTLE    false
#define HAS_ACCELERATOR false
#define HAS_BRAKE       false
#define HAS_STEERING    false

Joystick_ joystick(JOYSTICK_DEFAULT_REPORT_ID, JOYSTICK_TYPE_GAMEPAD,
                   NUM_BUTTONS, NUM_HATS, HAS_X_AXIS, HAS_Y_AXIS, HAS_Z_AXIS, HAS_RX_AXIS, HAS_RY_AXIS, HAS_RZ_AXIS,
                   HAS_RUDDER, HAS_THROTTLE, HAS_ACCELERATOR, HAS_BRAKE, HAS_STEERING);

int constrain_map(long x, long oldRangeMin, long oldRangeMax, long newRangeMin, long newRangeMax){
  int newX = constrain(x, oldRangeMin, oldRangeMax);
  return map(newX, oldRangeMin, oldRangeMax, newRangeMin, newRangeMax);
}

void setup() {
  #if DEBUG
  // Initialise Serial Connection
  Serial.begin(115200);
  #endif

  // Initialise Button Pins
  for (int i = 0; i < NUM_BUTTONS; i++){
    pinMode(pinToButton[i], INPUT_PULLUP);
  }

  // Initialise Hat Pins
  for (int i = 0; i < NUM_HAT_BUTTONS; i++){
    pinMode(pinToHat[i], INPUT_PULLUP);
  }

  // Initialise Joystick Library
  joystick.begin();
}

void loop() {
  // Handle Buttons
  for (int i = 0; i < NUM_BUTTONS; i++) {
    int currentButtonState = !digitalRead(pinToButton[i]);
    #if DEBUG
    Serial.print(buttonName[i] + " = " + currentButtonState + " ");
    #endif
    if (currentButtonState != lastButtonState[i]) {
      joystick.setButton(i, currentButtonState);
      lastButtonState[i] = currentButtonState;
    }
  }
  #if DEBUG
  Serial.println();
  #endif

  // Handle D-Pad
  bool hatChanged = false;
  for (int i = 0; i < NUM_HAT_BUTTONS; i++) {
    int currentButtonState = !digitalRead(pinToHat[i]);
    #if DEBUG
    Serial.print(hatName[i] + " = "+ currentButtonState+ " ");
    #endif
    if (currentButtonState != lastHatState[i]) {
      hatChanged = true;
      lastHatState[i] = currentButtonState;
    }
  }

  if(hatChanged){
    int numPressed = lastHatState[0] + lastHatState[1] + lastHatState[2] + lastHatState[3];
    // Only allow 1 button or 2 adjacent buttons to be pressed
    if (numPressed < 1 || numPressed > 2) lastHatAngle = JOYSTICK_HATSWITCH_RELEASE;
    // Ordinals or Diagonals
    else if(lastHatState[0] == 1 && lastHatState[1] == 1) lastHatAngle =  45; // NE
    else if(lastHatState[1] == 1 && lastHatState[2] == 1) lastHatAngle = 135; // SE
    else if(lastHatState[2] == 1 && lastHatState[3] == 1) lastHatAngle = 225; // SW
    else if(lastHatState[3] == 1 && lastHatState[0] == 1) lastHatAngle = 315; // NW
    // Invalid Combos: Up + Down, Left + Right
    else if(lastHatState[0] == 1 && lastHatState[2] == 1) lastHatAngle = JOYSTICK_HATSWITCH_RELEASE;
    else if(lastHatState[1] == 1 && lastHatState[3] == 1) lastHatAngle = JOYSTICK_HATSWITCH_RELEASE;
    // Cardinals or Non-Diagonals
    else if(lastHatState[0] == 1) lastHatAngle =   0; // N
    else if(lastHatState[1] == 1) lastHatAngle =  90; // E
    else if(lastHatState[2] == 1) lastHatAngle = 180; // S
    else if(lastHatState[3] == 1) lastHatAngle = 270; // W
    else lastHatAngle = JOYSTICK_HATSWITCH_RELEASE;
    joystick.setHatSwitch(HAT_INDEX, lastHatAngle);
  }

  #if DEBUG
  Serial.print("Hat Angle = ");
  Serial.println(lastHatAngle);
  #endif

  // Handle Analog
  for (int i = 0; i < NUM_ANALOG; i++) {
    int currentState = analogRead(pinToAnalog[i]);
    #if MAP_ANALOG
    currentState = constrain_map(currentState, pinRange[i][0], pinRange[i][1], LIB_MIN, LIB_MAX);
    #endif
    #if USE_DEADZONE
    if(i < JOYSTICK_POS && ((LIB_MAX / 2 - STICK_DEADZONE) < currentState && currentState  < (LIB_MAX / 2 + STICK_DEADZONE))) currentState = 512;
    #endif
    #if DEBUG
    Serial.print(analogName[i] + " = " + currentState + " ");
    #endif
    lastAnalogState[i] = currentState;
  }
  #if DEBUG
  Serial.println();
  #endif

  // Left Stick
  joystick.setXAxis(lastAnalogState[0]);
  joystick.setYAxis(lastAnalogState[1]);
  // Right Stick
  joystick.setRxAxis(lastAnalogState[2]);
  joystick.setRyAxis(lastAnalogState[3]);
  // Triggers
  #if SEPARATE_TRIGGERS
  joystick.setZAxis(lastAnalogState[4]);
  joystick.setRzAxis(lastAnalogState[5]);
  #else
  lastAnalogState[4] = map(lastAnalogState[4], LIB_MIN, LIB_MAX, LIB_MIN, LIB_MAX / 2);
  lastAnalogState[5] = map(lastAnalogState[5], LIB_MIN, LIB_MAX, LIB_MIN, LIB_MAX / 2);
  int stickValue = map(512 + lastAnalogState[4] - lastAnalogState[5], LIB_MIN + 1, LIB_MAX, LIB_MIN, LIB_MAX);
  joystick.setZAxis(stickValue);
  #endif

  #if DEBUG
  // Delay to read Serial console
  delay(1000);
  #else
  // Delay for responsive controls
  delay(16);
  #endif
}

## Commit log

2022-05-01 Add Version 1.0
    [joystick.brd, joystick.sch]
2022-05-01 Update Resources
    [NANO33BLE_V2.0.brd, NANO33BLE_V2.0.sch]
2022-05-17 Add Version 1.1
    [Drill_NPTH_Through.DRL, Drill_PTH_Through.DRL, Gerber_BoardOutlineLayer.GKO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]
2022-05-17 Fix Case Error in V1.1 Readme
2022-06-05 Add V1.2
    [Drill_NPTH_Through.DRL, Drill_PTH_Through.DRL, Gerber_BoardOutlineLayer.GKO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]
2022-06-15 Fix Triggers map Range in V1.1 and V1.2 Code
    [code.ino]
2022-06-20 Fix Start and Select Positions in V1.1 and V1.2 code
    [code.ino]
2022-06-26 Fix Inverted DEBUG Check for Serial Initialisation
    [code.ino]
2022-07-08 Add Version 2.0
    [Drill_PTH_Through.DRL, Gerber_BoardOutlineLayer.GKO, Gerber_BottomLayer.GBL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]

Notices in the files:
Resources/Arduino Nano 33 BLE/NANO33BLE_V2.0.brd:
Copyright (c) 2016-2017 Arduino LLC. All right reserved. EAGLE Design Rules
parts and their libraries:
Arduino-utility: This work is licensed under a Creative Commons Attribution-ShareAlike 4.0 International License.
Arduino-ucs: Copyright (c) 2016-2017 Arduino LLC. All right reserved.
